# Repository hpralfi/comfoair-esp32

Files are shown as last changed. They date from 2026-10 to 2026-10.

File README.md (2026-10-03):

# comfoair-esp32

**Zehnder ComfoAir, StorkAir WHR oder Wernig G90 in Home Assistant einbinden — lokal, ohne Cloud und ohne MQTT.**

[English](README.en.md) · [Projektseite](https://hpralfi.github.io/comfoair-esp32/)

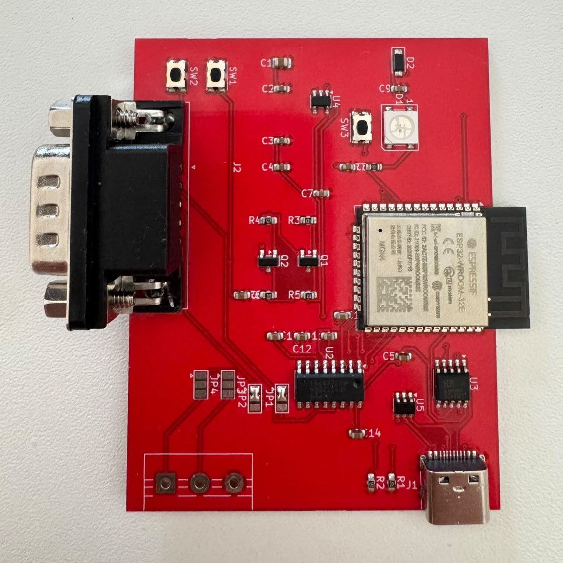
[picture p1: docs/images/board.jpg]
comfoair-esp32 Platine


Eine kleine ESP32-Platine für die Buchse **„RS232 PC“** von Lüftungsgeräten mit der Zehnder-Steuerplatine CA350. Sie läuft mit [ESPHome](https://esphome.io) und erscheint in Home Assistant mit über 40 Entitäten: Temperaturen, Lüftungsstufe, Ventilatorleistung und Drehzahl, Bypass, Filterzustand, Frostschutz, Betriebsstunden.

Entstanden ist sie als Ersatz für einen Gira HomeServer mit Moxa-Seriell-Gateway an einer Wernig G90-380. Dort läuft sie seit Oktober 2026.

## Funktionen

- **Native Home-Assistant-Anbindung** über die ESPHome-API — kein MQTT-Broker, keine Cloud
- **Alle Werte des Geräts**: vier Temperaturen, Stufe, Leistung und Drehzahl der Ventilatoren, Bypass, Filter, Frostschutz, Vorheizung, Betriebsstunden je Stufe
- **Steuern**: Lüftungsstufe 0–3, Komforttemperatur, Stufenwerte in Prozent, Stoßlüften-Taster auf der Platine
- **Schalter für das Bedienteil**: CC-Ease / CC-Luxe parallel weiter nutzen oder dunkel schalten, sodass nur Home Assistant bedient (siehe [RS232-Modus](#rs232-modus-und-das-bedienteil))
- **Eigene Weboberfläche** im Browser (mit Anmeldung): Stufenwahl, Wärmetauscher-Schaubild mit allen vier Temperaturen, Ventilatoren, Filterwarnung, Einstellungen, Live-Log, Firmware-Update per Datei — auch ohne Home Assistant, am Handy wie am PC
- **Updates über WLAN** nach dem ersten Flashen
- **USB-C** für Versorgung und Programmierung (CH340K an Bord, automatischer Wechsel in den Bootloader)
- **Zweiter RS232-Kanal** an einer Schraubklemme, vorgesehen für einen späteren Proxy-Betrieb des Bedienteils
- Status-LED (WS2812B) und ein frei belegbarer Taster

## In Home Assistant

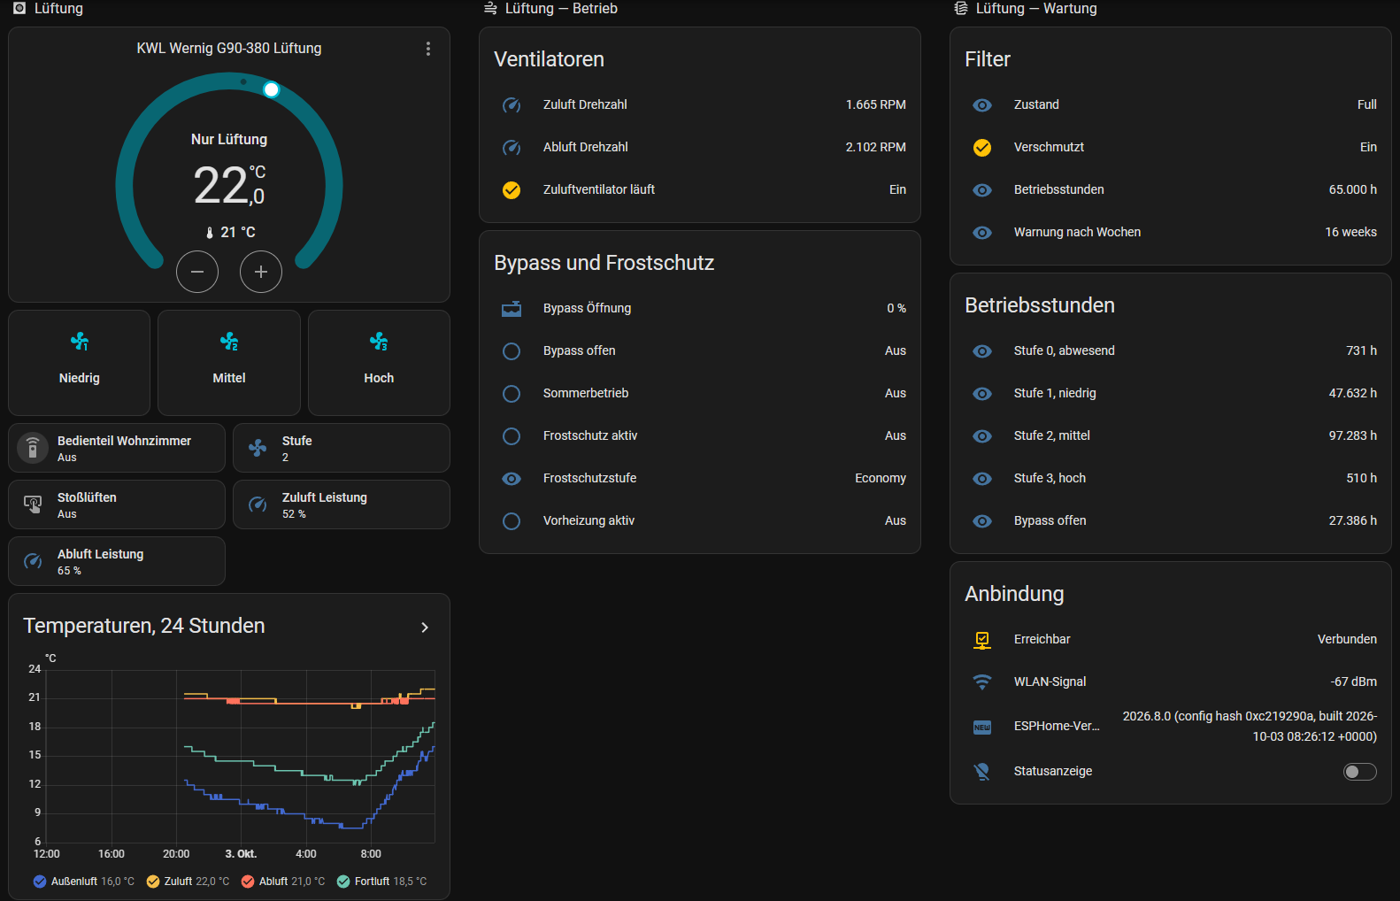
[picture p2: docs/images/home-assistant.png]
Home-Assistant-Dashboard


Beispiel-Dashboard: Stufenknöpfe, Schalter für das Bedienteil, Ventilatoren, Bypass, Filter, Betriebsstunden und Temperaturverlauf über 24 Stunden.

## Weboberfläche

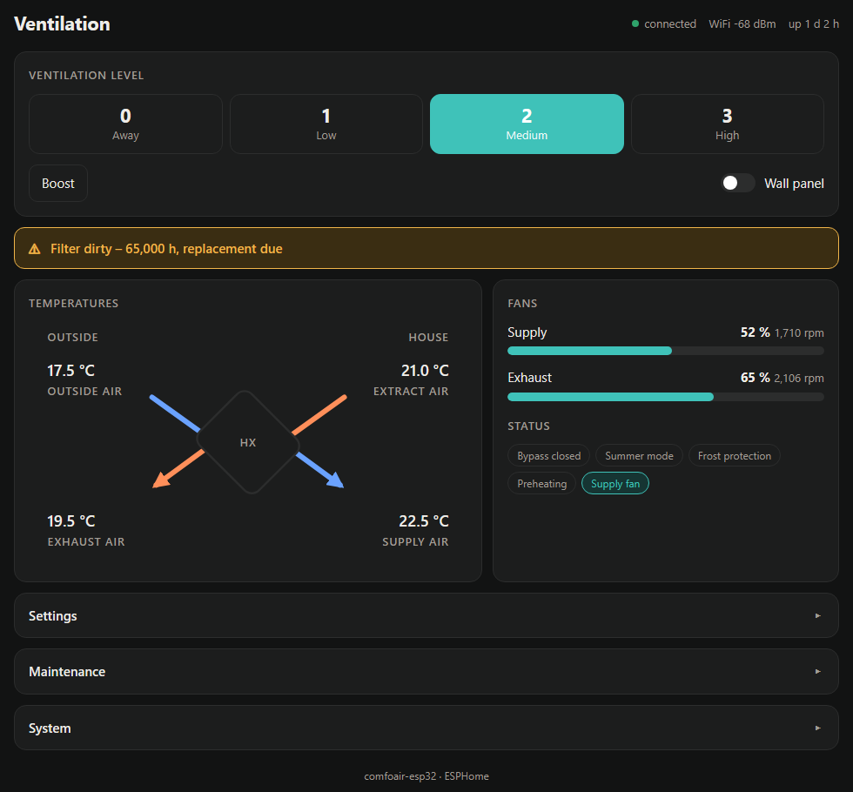
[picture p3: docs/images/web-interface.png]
Weboberfläche


Unter `http://<adresse-der-platine>/`, eingebettet in die Firmware ([`firmware/webui/comfoair-ui.js`](firmware/webui/comfoair-ui.js)), braucht kein Internet. Wer die Standardansicht von ESPHome bevorzugt, entfernt in der Konfiguration die Zeilen `js_url` und `js_include`.

## Hardware

| | |
|---|---|
| Größe | 70 × 55 mm, 2 Lagen, 1,6 mm |
| Prozessor | ESP32-WROOM-32E (WLAN, Leiterplattenantenne) |
| Pegelwandler | MAX3232 (2 Kanäle) |
| USB | USB-C, CH340K, ESD-Schutz USBLC6 |
| Versorgung | 5 V über USB-C, Regler AP2112K 3,3 V, unter 1 W |
| Anschluss Gerät | **DB9-Stecker**, DTE-Belegung: Pin 2 RX, Pin 3 TX, Pin 5 GND |
| Zweiter Anschluss | 3-polige Schraubklemme (RS232-Kanal 2) |
| Lötbrücken | JP1/JP2 kreuzen RX/TX am DB9 bei Bedarf |

Der DB9 ist belegt wie bei einer Moxa NPort 5110: Hängt am Gerät schon ein Seriell-Gateway oder PC-Kabel, dieses abstecken und die Platine mit demselben Kabel anschließen. An der Wernig G90-380 war kein Kreuzen nötig.

Schaltplan: [`hardware/schematic.pdf`](hardware/schematic.pdf) · KiCad-Projekt: [`hardware/kicad/`](hardware/kicad/) · Fertigungsdaten: [`hardware/production/`](hardware/production/)

## Kompatible Geräte

Das ComfoAir-Seriellprotokoll sprechen viele Geräte und ihre Handelsmarken-Varianten. Die meisten Kompatibilitätsangaben im Netz sind aus derselben Protokollbeschreibung abgeschrieben — deshalb trennt diese Liste **nachgewiesene** von nur **gelisteten** Geräten.

| Gerät | Marke | Status | Hinweis |
|---|---|---|---|
| G90-380 (CS / Luxe) | Wernig | ✅ **mit dieser Platine nachgewiesen** | meldet „CA350 luxe“, Firmware 3.20 |
| G90-160 | Wernig | ✅ nachgewiesen (andere Projekte) | openHAB-Binding |
| ComfoAir 350 | Zehnder | ✅ nachgewiesen (andere Projekte) | Referenzgerät des Protokolls |
| ComfoAir 160 | Zehnder | ✅ nachgewiesen (andere Projekte) | esphome-comfoair |
| ComfoD 450 | Zehnder | ✅ nachgewiesen (andere Projekte) | |
| G90-200 CS | Wernig | 🟡 wahrscheinlich | „RS232 PC“ im Schaltplan |
| ComfoAir 200 / 500 / 550 | Zehnder | 🟡 wahrscheinlich | gelistet, kein Testbericht |
| ComfoD 300 / 350 / 550 | Zehnder | 🟡 wahrscheinlich | gelistet |
| WHR 920 / 930 / 950 / 960 | J.E. StorkAir | 🟡 wahrscheinlich | gelistet |
| Santos 370 DC | Paul | 🟡 wahrscheinlich | gelistet |
| G90-300 | Wernig | ❔ ungeprüft | Schnittstelle nicht bestätigt |
| ComfoAir Q350 / Q450 / Q600, Wernig Q350 / Q600 | Zehnder / Wernig | ❌ nicht kompatibel | CAN / ComfoNet |
| ComfoAir E300 / E350 / E400 | Zehnder | ❌ nicht kompatibel | Modbus RTU (RS485) |
| Novus 300 | Paul | ❌ nicht kompatibel | RS485 |
| Vitovent 300-W | Viessmann | ❌ nicht kompatibel | OpenTherm / Modbus |

**Ein 🟡-Gerät getestet?** Bitte ein Issue anlegen — es wandert dann zu ✅.

### So prüfst du dein Gerät

1. **Typenschild**: eines der Modelle oben. Ein „Q“ oder „E“ im Modellnamen heißt: passt nicht.
2. **Bedienteil**: CC-Ease (Drehrad mit Display), CC-Luxe oder die alte ComfoSense sind gute Zeichen. ComfoConnect, ComfoSense C oder ein Touch-Display deuten auf die Q-Plattform.
3. **Steuerplatine**: CA350 / CA550 mit einem Anschluss **„RS232“** oder **„RS232 PC“**. Bei manchen Geräten ist das keine DB9-Buchse, sondern RJ45 oder Schraubklemmen (RX/TX/GND) — dann braucht es ein Adapterkabel.
4. Auf der Konnektorplatine der Wernig G90-380 CS gibt es zusätzlich **RS485**-Klemmen („Entalpy“, „Hybalans“). Die sind für Zubehör, **nicht** der PC-Anschluss.

## Platine bekommen

### Fertige Platine

Bestückte und geprüfte Platinen: DB9 und Schraubklemme gelötet, Lötbrücken gesetzt, Firmware aufgespielt.

**Fertige Platinen sind in Vorbereitung.** Melde dich unverbindlich — mit Gerätemodell und Land, dann sage ich Bescheid, sobald es losgeht:

📧 **[office@gfrerrer.at](mailto:office@gfrerrer.at?subject=comfoair-esp32%20-%20Interesse)**

### Selbst bauen

1. Bei [JLCPCB](https://jlcpcb.com) mit Bestückung (PCBA) bestellen: [`gerber.zip`](hardware/production/gerber.zip), [`jlcpcb-bom.csv`](hardware/production/jlcpcb-bom.csv) und [`jlcpcb-cpl.csv`](hardware/production/jlcpcb-cpl.csv) hochladen. Die Bestückungsdatei enthält bereits die Dreh- und Lagekorrekturen, die JLCPCB braucht. Die LCSC-Nummern beim Bestellen auf Lagerbestand prüfen.
2. Von Hand löten: **J2** (DB9-Stecker, gewinkelt, mit Befestigungsbohrungen) und **J3** (3-polige Schraubklemme, 5,08 mm). Auch die beiden Befestigungslaschen des DB9 verlöten — sie tragen die Steckkraft. Sie hängen an der Massefläche: breite Meißelspitze, etwa 380 °C.
3. **Lötbrücken JP1 und JP2 auf Pad 1–2 schließen.** Sie sind ab Werk offen — ohne sie ist der DB9 nicht mit dem MAX3232 verbunden und das Gerät bleibt stumm. (Pad 2–3 kreuzt RX/TX, falls das Kabel es braucht.)
4. Firmware aufspielen (unten).

## Firmware

Die Platine nutzt einen Fork von [wichers/esphome-comfoair](https://github.com/wichers/esphome-comfoair) mit zwei Ergänzungen: RS232-Modus setzen (Kommando `0x9B`) und den vom Gerät gemeldeten Modus auswerten (`0x9C`).

1. [`firmware/comfoair-esp32.yaml`](firmware/comfoair-esp32.yaml), den Ordner [`firmware/webui/`](firmware/webui/) und [`firmware/secrets.yaml.example`](firmware/secrets.yaml.example) (als `secrets.yaml`) in den ESPHome-Ordner kopieren und ausfüllen.
2. Erstes Flashen über USB-C, z. B. mit dem ESPHome-Dashboard oder `esphome run comfoair-esp32.yaml`. Die Platine wechselt selbst in den Bootloader.
3. Danach laufen Updates über WLAN.
4. Home Assistant findet das Gerät; den API-Schlüssel eingeben, wenn danach gefragt wird.
5. Webinterface: `http://<adresse-der-platine>/`, Anmeldung mit `web_username` / `web_password` aus `secrets.yaml`. Dort lassen sich auch neue Firmware-Dateien (`.bin`) hochladen.

## RS232-Modus und das Bedienteil

Das Gerät kennt mehrere RS232-Modi. Gemessen an einer CA350 mit Firmware 3.20:

| Modus | Bedeutung | Ergebnis |
|---|---|---|
| 1 „nur PC“ | | **wird quittiert, aber ignoriert** |
| 3 „PC Master“ | | angenommen — **Bedienteil wird dunkel** |
| 0 „Ende“ (aus 3) | zurück auf 2 „nur CC-Ease“ | Bedienteil aktiv, **Home Assistant liest und schaltet trotzdem** |

Der Schalter **„Wall panel“** in Home Assistant wählt zwischen beiden: aus = Modus 3 (Bedienteil dunkel), an = Modus 2 (beide parallel). Nach einem Stromausfall startet das Gerät in Modus 2; die Platine prüft den gemeldeten Modus jede Minute und stellt die Einstellung wieder her.

## Einbau

- Die Platine hängt **nur an der Kleinspannungs-Schnittstelle RS232**. Den Netzspannungsteil des Geräts nicht öffnen.
- Versorgung über ein beliebiges USB-C-Netzteil (5 V, 0,5 A reichen).
- Das Antennenende der Platine frei von Metall halten, dann ist der WLAN-Empfang gut.
- Auf der RS232-Leitung darf nur **ein Master** sprechen: anderes Gateway oder PC vorher abstecken.

## Lizenz

- Hardware (`hardware/`): [CERN-OHL-S-2.0](LICENSE-CERN-OHL-S-2.0)
- Firmware-Konfiguration und Dokumentation: [GPL-3.0](LICENSE-GPL-3.0), wie die zugrunde liegende ESPHome-Komponente

## Haftungsausschluss

Ein unabhängiges Hobbyprojekt ohne Verbindung zu Zehnder Group, J.E. StorkAir, Wernig oder Paul. Marken- und Modellnamen dienen nur zur Angabe der Kompatibilität. Nutzung auf eigene Gefahr.

## Dank

- [wichers/esphome-comfoair](https://github.com/wichers/esphome-comfoair) — die ESPHome-Komponente
- Die ComfoAir-Protokollbeschreibung der Community sowie die Projekte FHEM, openHAB und hacomfoairmqtt

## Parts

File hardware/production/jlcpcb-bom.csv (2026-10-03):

Comment | Designator | Footprint | LCSC Part #
CC0603KRX7R9BB104 | C2,C4,C5,C7,C8,C9,C10,C11,C12,C13,C14 | C_0603_1608Metric | C14663
0603WAF1002T5E | R5,R6 | R_0603_1608Metric | C25804
0603WAF1202T5E | R3,R4 | R_0603_1608Metric | C22790
1N4148W | D2 | D_SOD-123 | C81598
CL10A105KB8NNNC | C3,C6 | C_0603_1608Metric | C15849
CL21A226MAQNNNE | C1 | C_0805_2012Metric | C45783
0603WAF3300T5E | R7 | R_0603_1608Metric | C23138
0603WAF5101T5E | R1,R2 | R_0603_1608Metric | C23186
AP2112K-3.3TRG1 | U4 | SOT-23-5 | C23380830
CH340K | U3 | SSOP-10-1EP_3.9x4.9mm_P1mm_EP2.1x3.3mm | C18208922
ESP32-WROOM-32E-N4 | U1 | ESP32-WROOM-32E | C701341
SP3232EEN-L/TR | U2 | SOIC-16_3.9x9.9mm_P1.27mm | C9378
MMBT3904 | Q1,Q2 | SOT-23 | C7420353
KMR221GLFS | SW1,SW2,SW3 | SW_Push_1P1T_NO_CK_KMR2 | C72443
TYPE-C-31-M-12 | J1 | USB_C_Receptacle_HRO_TYPE-C-31-M-12 | C165948
USBLC6-2SC6 | U5 | SOT-23-6 | C2827654
XL-5050RGBC-2812B | D1 | LED_WS2812B_PLCC4_5.0x5.0mm_P3.2mm | C2843785

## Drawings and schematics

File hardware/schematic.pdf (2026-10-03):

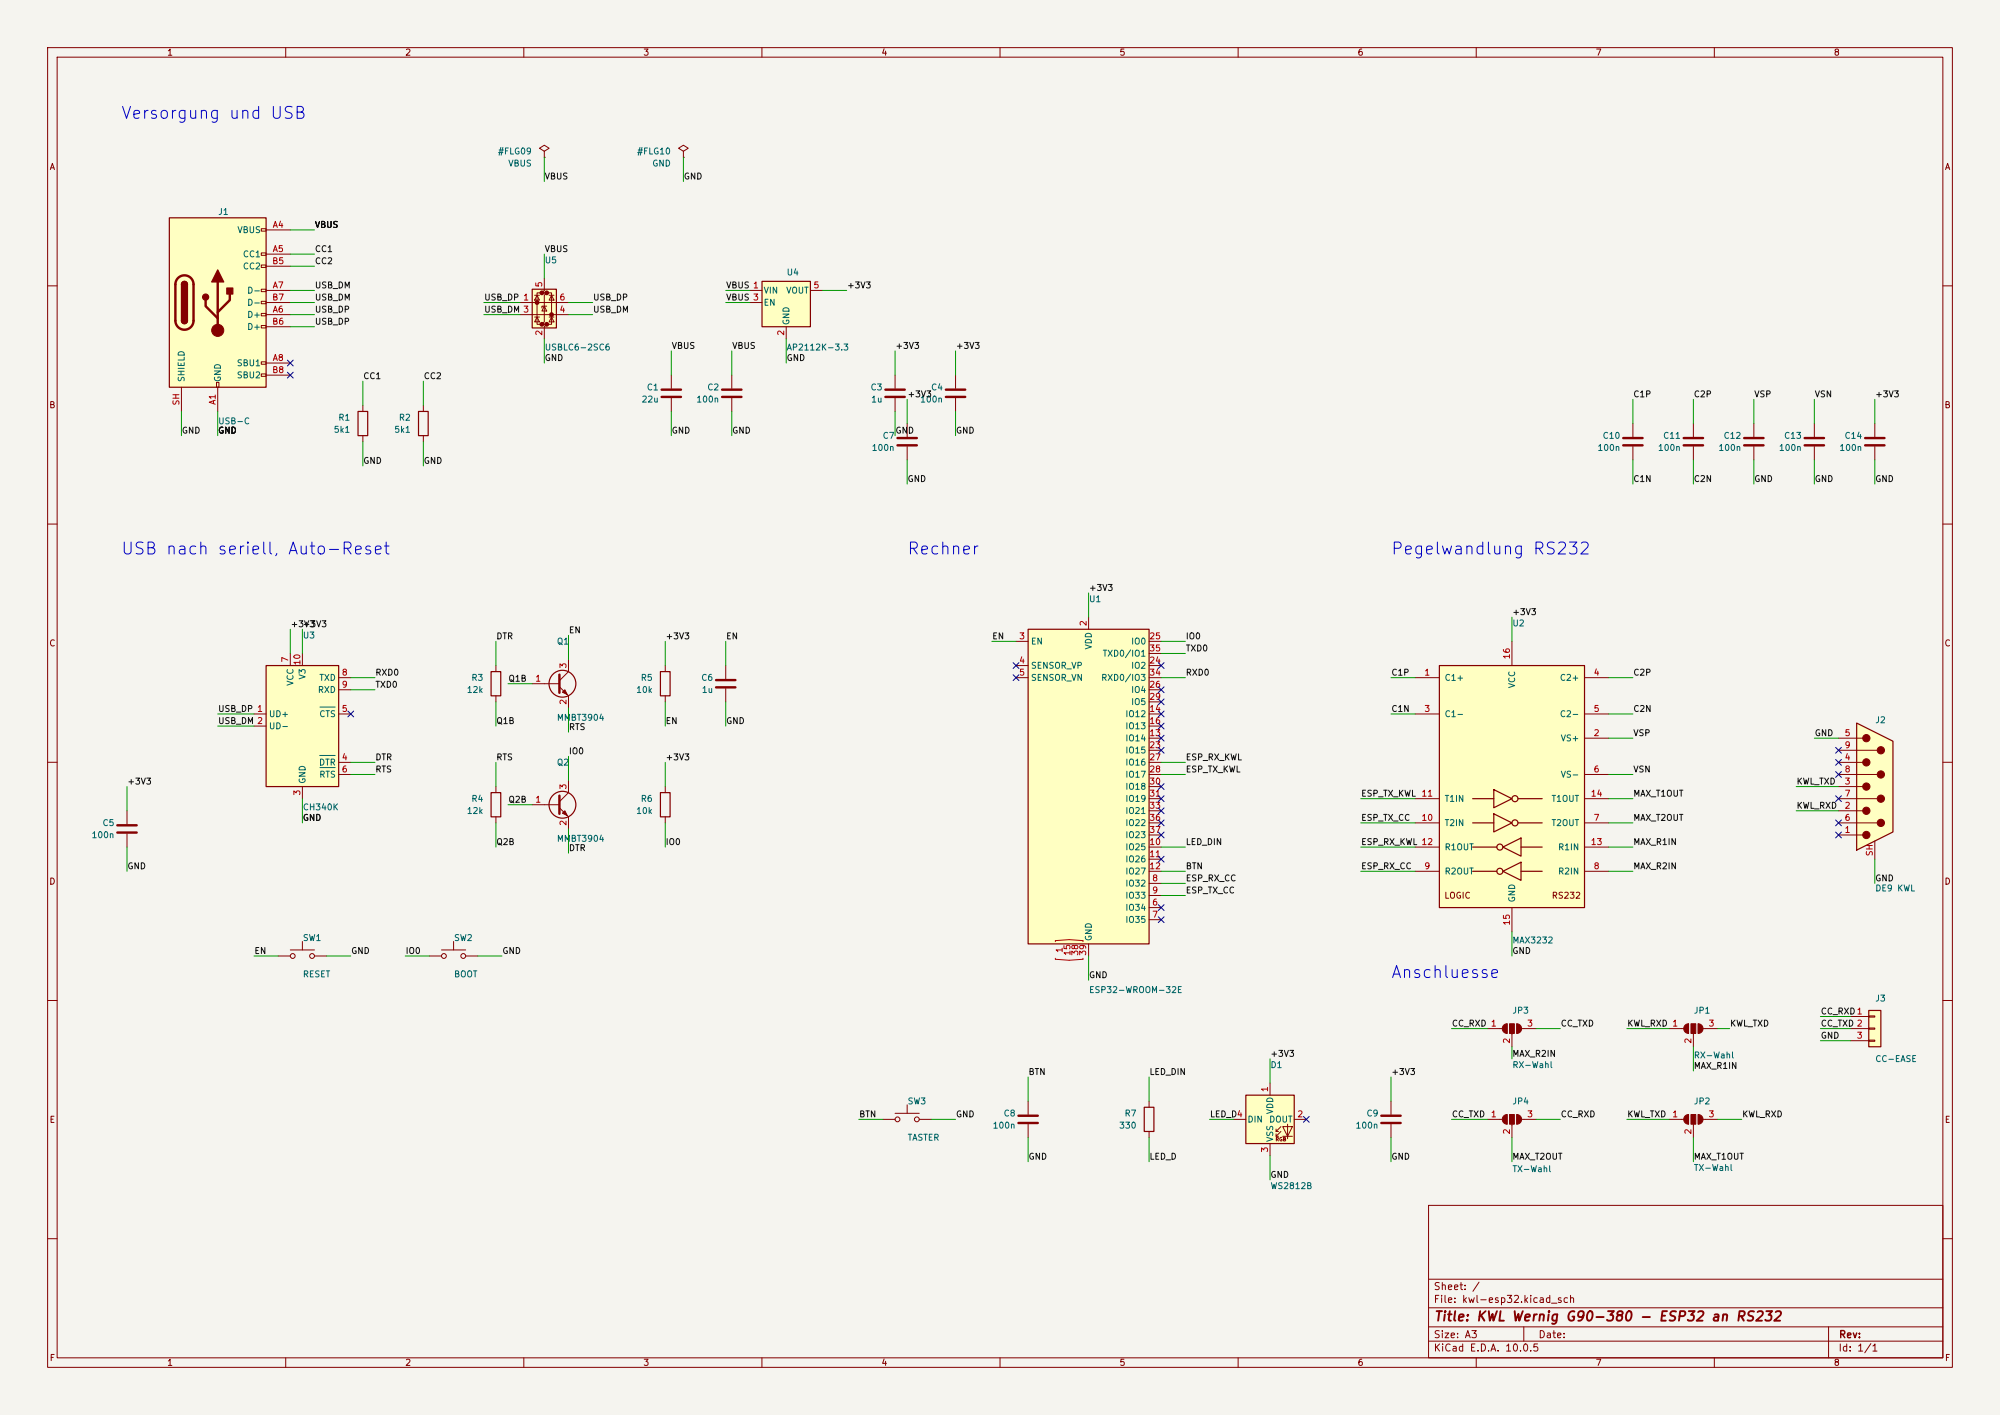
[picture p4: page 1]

3 DTR 4 CTS 5 RTS 6 VCC

Sheet: /
File: kwl-esp32.kicad_sch
Title: KWL Wernig G90-380 - ESP32 an RS232

Size: A3 | Rev: | F Date:
KiCad E.D.A. 10.0.5 | Id: 1/1

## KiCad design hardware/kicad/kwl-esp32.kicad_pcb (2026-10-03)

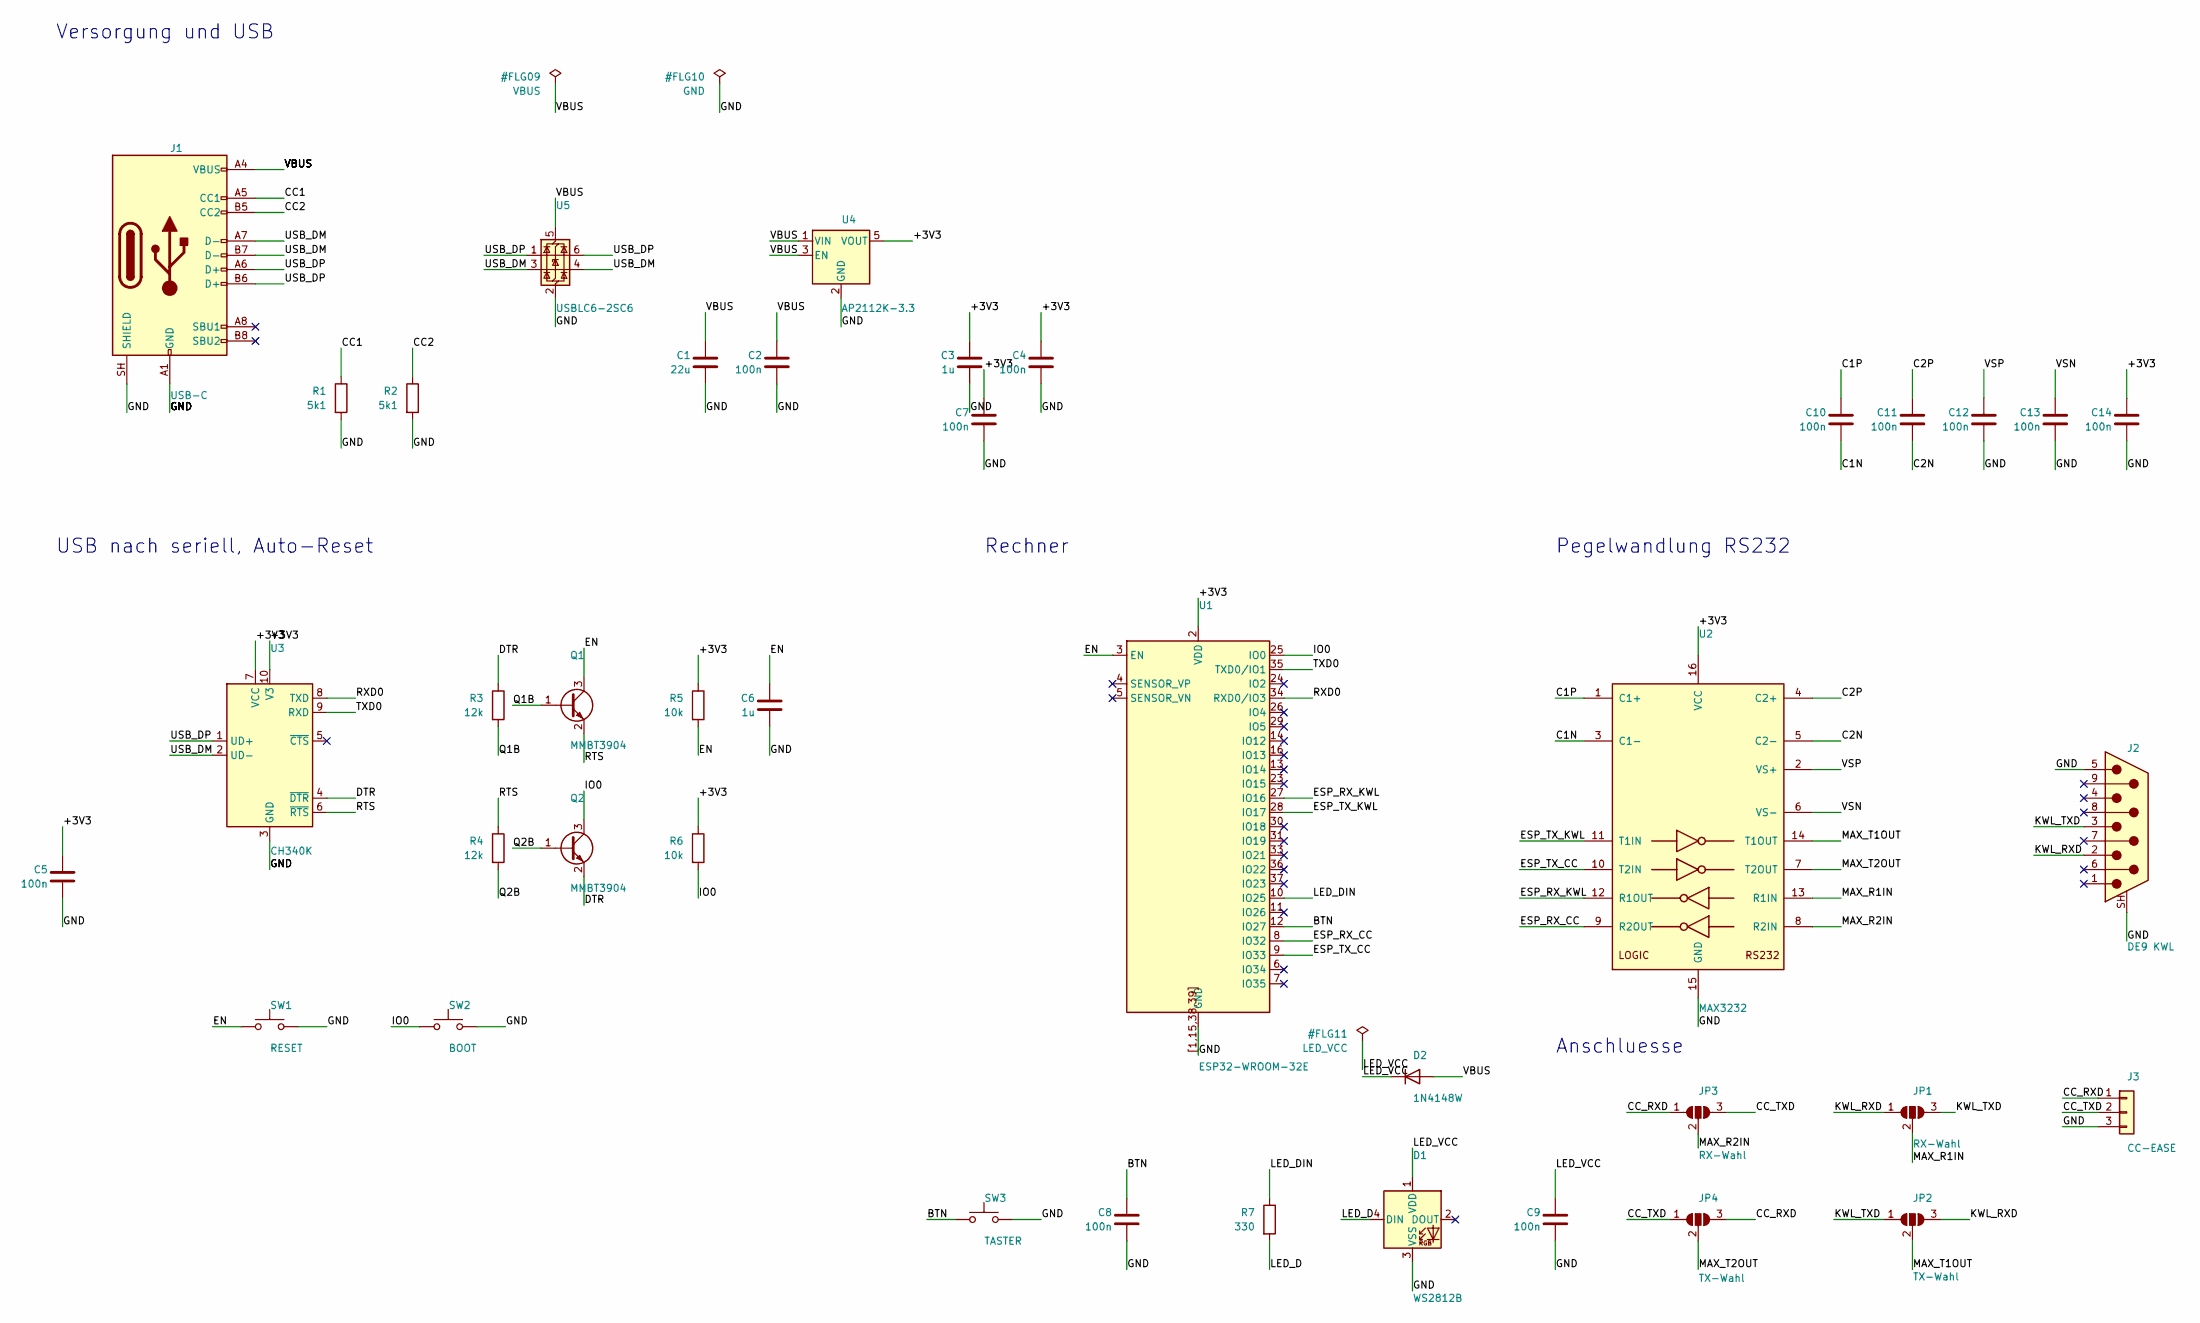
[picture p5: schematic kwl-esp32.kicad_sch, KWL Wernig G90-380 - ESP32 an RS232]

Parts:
C1: 22u; C_0805_2012Metric
C2, C4, C5, C7, C8, C9, C10, C11, C12, C13, C14: 100n; C_0603_1608Metric
C3, C6: 1u; C_0603_1608Metric
D1: WS2812B; LED_WS2812B_PLCC4_5.0x5.0mm_P3.2mm
D2: 1N4148W; D_SOD-123
J1: USB-C; USB_C_Receptacle_HRO_TYPE-C-31-M-12
J2: DE9 KWL; DSUB-9_Pins_Horizontal_P2.77x2.84mm_EdgePinOffset4.94mm_Hou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
J3: CC-EASE; TerminalBlock_MaiXu_MX126-5.0-03P_1x03_P5.00mm
JP1, JP3: RX-Wahl; SolderJumper-3_P1.3mm_Open_Pad1.0x1.5mm
JP2, JP4: TX-Wahl; SolderJumper-3_P1.3mm_Open_Pad1.0x1.5mm
Q1, Q2: MMBT3904; SOT-23
R1, R2: 5k1; R_0603_1608Metric
R3, R4: 12k; R_0603_1608Metric
R5, R6: 10k; R_0603_1608Metric
R7: 330; R_0603_1608Metric
SW1: RESET; SW_Push_1P1T_NO_CK_KMR2
SW2: BOOT; SW_Push_1P1T_NO_CK_KMR2
SW3: TASTER; SW_Push_1P1T_NO_CK_KMR2
U1: ESP32-WROOM-32E
U2: MAX3232; SOIC-16_3.9x9.9mm_P1.27mm
U3: CH340K; SSOP-10-1EP_3.9x4.9mm_P1mm_EP2.1x3.3mm
U4: AP2112K-3.3; SOT-23-5
U5: USBLC6-2SC6; SOT-23-6

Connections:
+3V3: C3.1, C4.1, C5.1, C7.1, C14.1, R5.1, R6.1, U1.2 (VDD), U2.16 (VCC), U3.7 (VCC), U3.10 (V3), U4.5 (VOUT)
BTN: C8.1, SW3.1, U1.12 (IO27)
C1N: C10.2, U2.3 (C1-)
C1P: C10.1, U2.1 (C1+)
C2N: C11.2, U2.5 (C2-)
C2P: C11.1, U2.4 (C2+)
CC1: J1.A5 (CC1), R1.1
CC2: J1.B5 (CC2), R2.1
CC_RXD: J3.1, JP3.1 (A), JP4.3 (B)
CC_TXD: J3.2, JP3.3 (B), JP4.1 (A)
DTR: Q2.2 (E), R3.1, U3.4 (~DTR)
EN: C6.1, Q1.3 (C), R5.2, SW1.1, U1.3 (EN)
ESP_RX_CC: U1.8 (IO32), U2.9 (R2OUT)
ESP_RX_KWL: U1.27 (IO16), U2.12 (R1OUT)
ESP_TX_CC: U1.9 (IO33), U2.10 (T2IN)
ESP_TX_KWL: U1.28 (IO17), U2.11 (T1IN)
GND: C1.2, C2.2, C3.2, C4.2, C5.2, C6.2, C7.2, C8.2, C9.2, C12.2, C13.2, C14.2, D1.3 (VSS), J1.A1 (GND), J1.A12 (GND), J1.B1 (GND), J1.B12 (GND), J1.SH (SHIELD), J2.5, J2.SH (PAD), J3.3, R1.2, R2.2, SW1.2, SW2.2, SW3.2, U1.1, U1.15, U1.38, U1.39, U1.[1,15,38,39] (GND), U2.15 (GND), U3.3 (GND), U3.11 (GND), U4.2 (GND), U5.2 (GND)
IO0: Q2.3 (C), R6.2, SW2.1, U1.25 (IO0)
KWL_RXD: J2.2, JP1.1 (A), JP2.3 (B)
KWL_TXD: J2.3, JP1.3 (B), JP2.1 (A)
LED_D: D1.4 (DIN), R7.2
LED_DIN: R7.1, U1.10 (IO25)
LED_VCC: C9.1, D1.1 (VDD), D2.1 (K)
MAX_R1IN: JP1.2 (C), U2.13 (R1IN)
MAX_R2IN: JP3.2 (C), U2.8 (R2IN)
MAX_T1OUT: JP2.2 (C), U2.14 (T1OUT)
MAX_T2OUT: JP4.2 (C), U2.7 (T2OUT)
Q1B: Q1.1 (B), R3.2
Q2B: Q2.1 (B), R4.2
RTS: Q1.2 (E), R4.1, U3.6 (~RTS)
RXD0: U1.34 (RXD0/IO3), U3.8 (TXD)
TXD0: U1.35 (TXD0/IO1), U3.9 (RXD)
USB_DM: J1.A7 (D-), J1.B7 (D-), U3.2 (UD-), U5.3 (I/O2), U5.4 (I/O2)
USB_DP: J1.A6 (D+), J1.B6 (D+), U3.1 (UD+), U5.1 (I/O1), U5.6 (I/O1)
VBUS: C1.1, C2.1, D2.2 (A), J1.A4 (VBUS), J1.A9 (VBUS), J1.B4 (VBUS), J1.B9 (VBUS), U4.1 (VIN), U4.3 (EN), U5.5 (VBUS)
VSN: C13.1, U2.6 (VS-)
VSP: C12.1, U2.2 (VS+)

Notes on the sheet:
Rechner
Pegelwandlung RS232
USB nach seriell, Auto-Reset
Anschluesse
Versorgung und USB

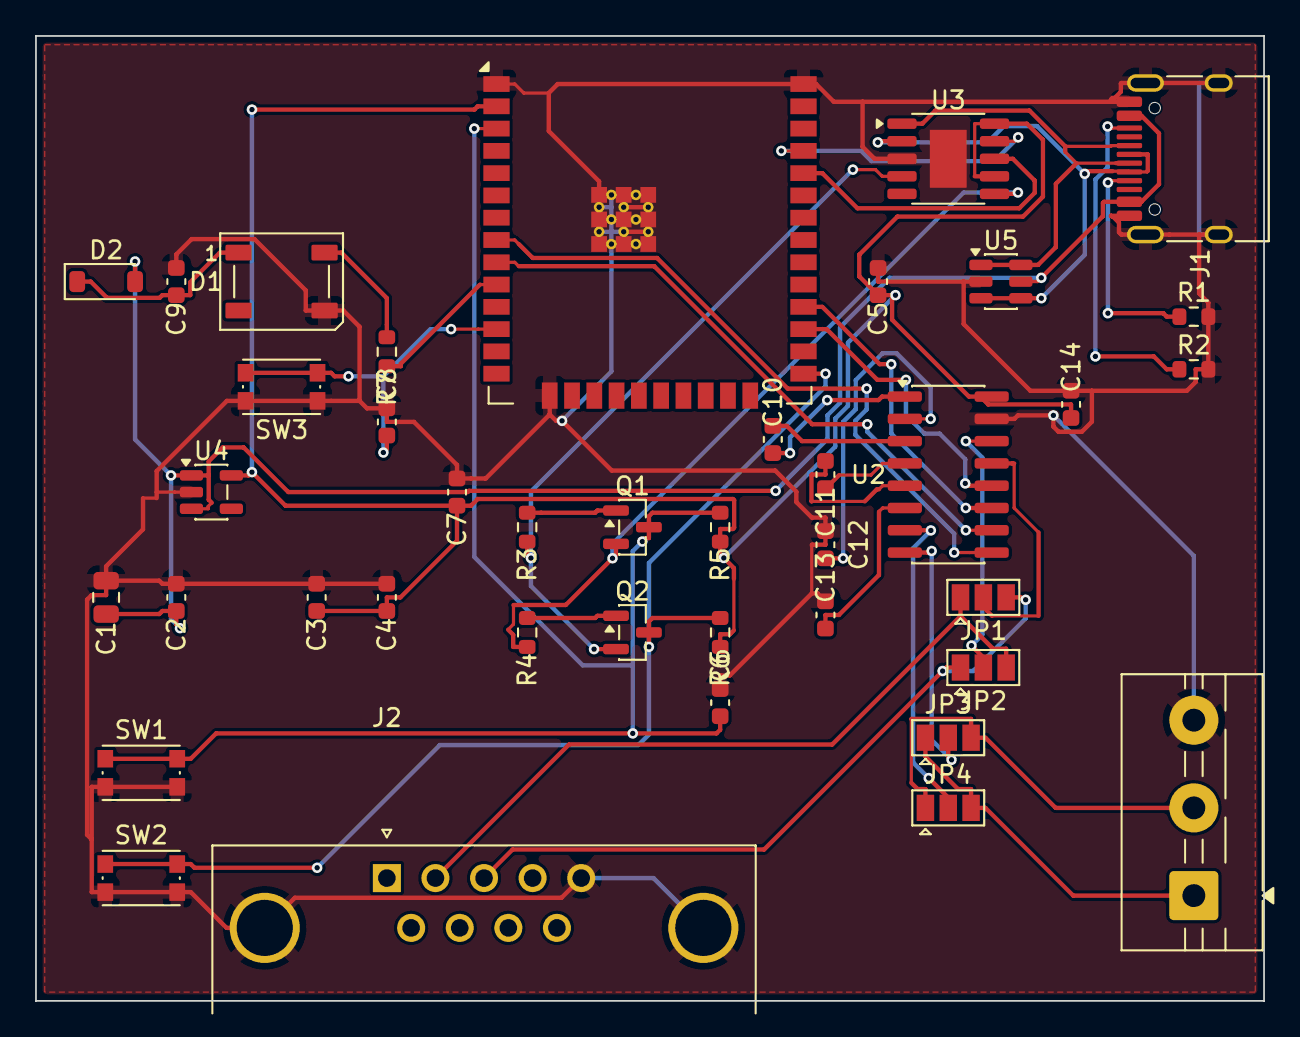
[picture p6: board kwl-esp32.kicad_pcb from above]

Board: 2 copper layers, 70.0 x 55.0 mm, 40 parts (0 on the bottom side), 37 nets.

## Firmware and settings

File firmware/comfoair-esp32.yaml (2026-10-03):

# comfoair-esp32 - ESPHome configuration
# Board:     comfoair-esp32 rev 1.0 (ESP32-WROOM-32E + MAX3232, DB9 male)
# Component: https://github.com/hpralfi/esphome-comfoair (branch pc-mode),
#            a fork of https://github.com/wichers/esphome-comfoair
# Unit:      ComfoAir serial protocol over the "RS232 PC" port (9600 8N1),
#            e.g. Zehnder ComfoAir 350 / Wernig G90-380 ("CA350 luxe")
#
# Copy secrets.yaml.example to secrets.yaml and fill in your values.

substitutions:
  node_name: comfoair-esp32
  device_name: "ComfoAir"

esphome:
  name: ${node_name}
  friendly_name: "${device_name}"
  comment: "Ventilation unit via RS232"
  on_boot:
    priority: -100
    then:
      # Give the component time for its first request cycle
      - delay: 15s
      - script.execute: apply_rs232_mode

# RS232 mode of the unit (command 0x9B), measured on a CA350 with firmware 3.20:
#   mode 1 "PC only"   -> acknowledged but ignored
#   mode 3 "PC master" -> wall panel (CC-Ease / CC-Luxe) goes dark, ESP controls
#   mode 0 "end"       -> from mode 3 back to 2 "CC-Ease only": panel active,
#                         the ESP can still read and switch levels
# After a power cut the unit starts in mode 2. The unit reports its mode
# (0x9C); the board compares it with the switch every minute and only sends
# a command if it differs.
script:
  # Boost: highest level, back to level 2 after 30 minutes.
  # mode: restart - pressing again starts the 30 minutes over.
  - id: boost
    mode: restart
    then:
      - lambda: 'id(comfoair_climate).set_level(3);'
      - delay: 30min
      - lambda: 'id(comfoair_climate).set_level(2);'
  - id: apply_rs232_mode
    then:
      - lambda: |-
          const uint8_t current = id(comfoair_climate).get_rs232_mode();
          if (id(wall_panel).state) {
            if (current != 2) id(comfoair_climate).set_rs232_mode(0);
          } else {
            if (current != 3) id(comfoair_climate).set_rs232_mode(3);
          }

interval:
  - interval: 1min
    then:
      - script.execute: apply_rs232_mode

switch:
  - platform: template
    id: wall_panel
    name: "Wall panel"
    web_server:
      sorting_group_id: grp_ventilation
    icon: mdi:remote
    optimistic: true
    # Default off = panel dark, Home Assistant is the only control.
    # Switch on to keep the CC-Ease usable in parallel.
    restore_mode: RESTORE_DEFAULT_OFF
    on_turn_on:
      - script.execute: apply_rs232_mode
    on_turn_off:
      - script.execute: apply_rs232_mode

esp32:
  board: wemos_d1_mini32
  framework:
    type: esp-idf

external_components:
  - source:
      type: git
      url: https://github.com/hpralfi/esphome-comfoair
      ref: pc-mode
    components: [comfoair]

wifi:
  ssid: !secret wifi_ssid
  password: !secret wifi_password
  # Mains powered: power saving only adds latency (360-820 ms with LIGHT)
  power_save_mode: NONE
  ap:
    ssid: ${node_name}-setup
    password: !secret wifi_fallback_ap_key

captive_portal:

# Native Home Assistant API - no MQTT needed
api:
  encryption:
    key: !secret api_encryption_key

ota:
  - platform: esphome
    password: !secret ota_password
  # Firmware upload through the web interface
  - platform: web_server

# Web interface at http://<device-ip>/ : live values, controls, settings and
# log. Authentication is required - without it anyone on the network could
# switch the unit or upload firmware.
web_server:
  port: 80
  version: 3
  # Custom UI (webui/comfoair-ui.js) instead of the default one, embedded in
  # flash - no internet needed. Remove these two lines for the stock UI.
  js_url: ""
  js_include: webui/comfoair-ui.js
  auth:
    username: !secret web_username
    password: !secret web_password
  sorting_groups:
    - id: grp_ventilation
      name: "Ventilation"
      sorting_weight: 10
    - id: grp_temperatures
      name: "Temperatures"
      sorting_weight: 20
    - id: grp_bypass
      name: "Bypass and frost protection"
      sorting_weight: 30
    - id: grp_maintenance
      name: "Filter and operating hours"
      sorting_weight: 40
    - id: grp_settings
      name: "Settings"
      sorting_weight: 50

logger:
  level: INFO

sensor:
  - platform: wifi_signal
    name: "WiFi signal"
    update_interval: 120s
    entity_category: diagnostic

text_sensor:
  - platform: version
    name: "ESPHome version"
    entity_category: diagnostic

binary_sensor:
  - platform: status
    name: "Status"
  # SW3 on the board: boost ventilation for 30 minutes, then back to level 2
  - platform: gpio
    id: boost_button
    name: "Boost button"
    web_server:
      sorting_group_id: grp_ventilation
    pin:
      number: GPIO27
      mode:
        input: true
        pullup: true
      inverted: true
    on_press:
      then:
        - script.execute: boost
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

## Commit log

2026-10-03 Initial release: ESP32 RS232 board for ComfoAir units
    Hardware (KiCad, schematic, JLCPCB production files), ESPHome
    configuration with wall panel switch, bilingual README and GitHub
    Pages product page with compatibility list.
    [jlcpcb-bom.csv, kwl-esp32.kicad_pcb, kwl-esp32.kicad_sch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]
2026-10-03 Projektseite: Anleitungslink auf die deutsche bzw. englische README
2026-10-03 Webinterface mit Anmeldung und Firmware-Update per Browser
2026-10-03 Eigene Weboberfläche mit Wärmetauscher-Schaubild und Boost-Knopf
